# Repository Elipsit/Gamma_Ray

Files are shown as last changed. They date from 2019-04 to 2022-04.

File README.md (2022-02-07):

# Gamma_Ray
## Project Description
This was a personal project to recreate a white paper from Analog Devices on using a PIN photodode as a Gamma Ray detector.

The original insparation was from a Hack-A-Day article [USE A CHEAP PIN DIODE AS A GEIGER COUNTER](https://hackaday.com/blog/?s=cheap+pin+diode)

## Results

The project was successful and when the comparator setpoint was set correctly it will chatter when placed near gamma ray emitting sources or strong background radiation.

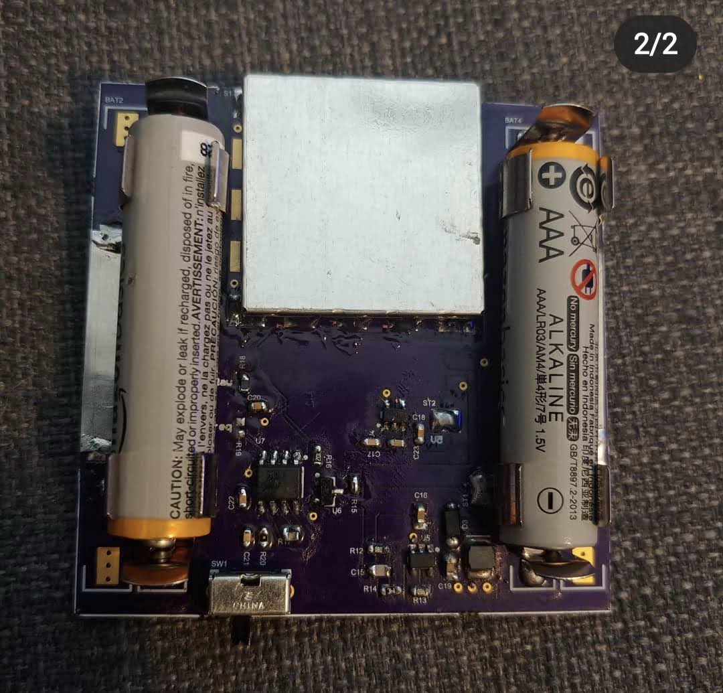
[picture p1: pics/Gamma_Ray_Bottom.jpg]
Bottom Pic


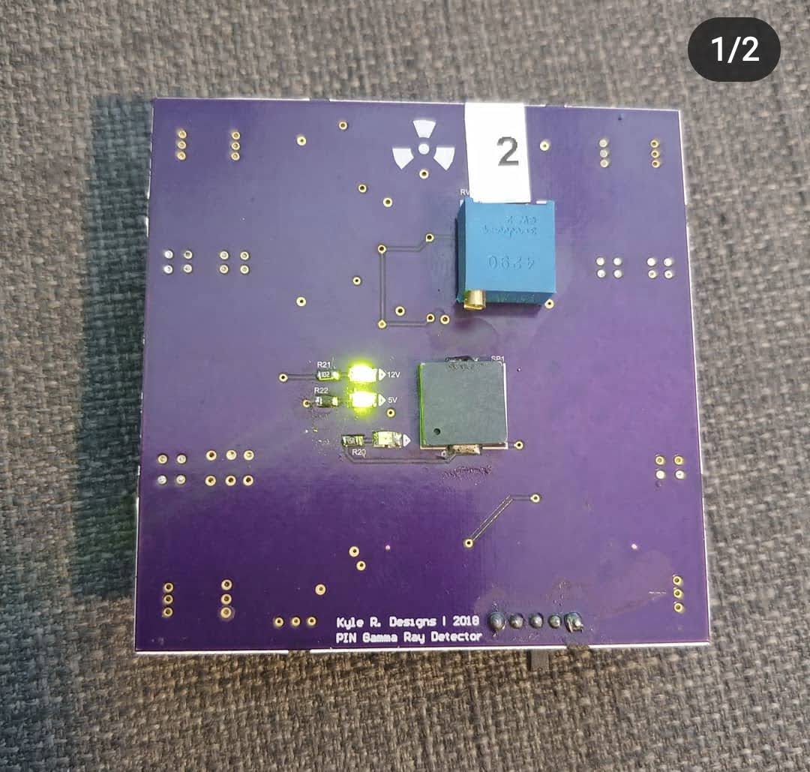
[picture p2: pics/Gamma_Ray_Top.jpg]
Top


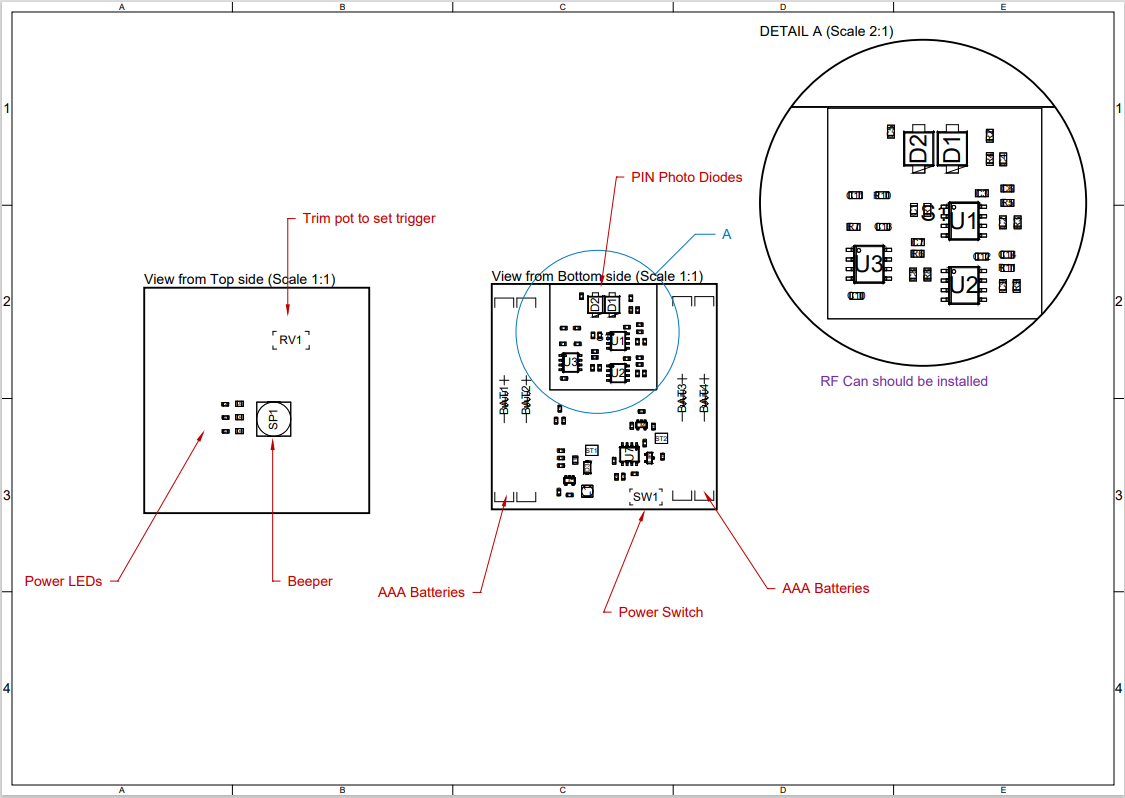
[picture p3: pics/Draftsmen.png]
draftsmen


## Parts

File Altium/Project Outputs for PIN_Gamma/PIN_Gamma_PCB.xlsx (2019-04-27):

Comment | Description | Designator | Digikey | Digikey Part | Digikey PartC | Digikey PartF | Footprint | LibRef | Quantity
U/MAX4477ASA+-ND | Dual Low-Noise, Low-Distortion, Wide-Band, Rail-to-Rail Op Amps | U1, U2 |  |  |  |  | SO8 | U/MAX4477ASA+-ND | 2
U/MAX987ESA+-ND | Comparator General Purpose CMOS, Push-Pull, Rail-to-Rail, TTL 8-SO | U3 |  |  |  |  | SO8 | U/MAX987ESA+-ND | 1
U/LM555CMX | 555 Type, Timer/Oscillator (Single) IC 8-SOIC | U7 |  |  |  |  | SO8 | U/LM555CMX | 1
U/AP1150ADS50 | IC REG LINEAR 5V 200MA SOT23-5 | U4 |  | AP1150ADS50CT-ND |  |  | SOT23-5 | U/AP1150ADS50 | 1
U/2N3904/SOT23 | TRANS NPN 40V 0.2A SOT23 | U6 |  | MMBT3904LT3GOSCT-ND |  |  | SOT23-3 | U/2N3904/SOT23 | 1
SW/SPDT/THT | SWITCH SLIDE SPDT 200MA 30V | SW1 |  | A107673-ND |  |  | SW/SPDT/THT | SW/SPDT/THT | 1
SP/Piezo | AUDIO PIEZO TRANSDUCER Max 12.5V 4KHZ SMD | SP1 |  | 490-9647-1-ND |  |  | AUDIO PIEZO | SP/Piezo | 1
Shark Tooth | Sharks Tooth Small | ST1, ST2 |  |  |  |  | SHARKTOOTH | Shark Tooth | 2
RV/10K/25Turn | TRIMMER 10K OHM 0.5W TH | RV1 |  | A105870-ND |  |  | 10K/25TN | RV/10K/25Turn | 1
RF Shield | SMS-403C & SMS-403F RF Shield Cover 1.058" (26.87mm) X 1.058" (26.87mm) Non-Vented Surface Mount | S1 |  |  | 1798-1210-ND | 1798-1211-1-ND | RF SHIELD | RF Shield | 1
R/976K/0603 | RES SMD 976K OHM 1% 1/10W 0603 | R13 |  | 311-976KHRCT-ND |  |  | R/0603 | R/976K/0603 | 1
R/287r/0603 | RES SMD 287 OHM 1% 1/10W 0603 | R22, R23 |  | 311-287HRCT-ND |  |  | R/0603 | R/287r/0603 | 2
R/150K/0603 | RES SMD 150K OHM 1% 1/10W 0603 | R10 |  | 311-150KGRDKR-ND |  |  | R/0603 | R/150K/0603 | 1
R/118K/0603 | RES SMD 118K OHM 1% 1/10W 0603 | R12 |  | 311-118KHRCT-ND |  |  | R/0603 | R/118K/0603 | 1
R/100K/0603 | RES SMD 100K OHM 1% 1/10W 0603 | R7 |  | 311-100KHRCT-ND |  |  | R/0603 | R/100K/0603 | 1
R/13K7/0603 | RES SMD 13.7K OHM 1% 1/10W 0603 | R14 |  | 311-13.7KHRCT-ND |  |  | R/0603 | R/13K7/0603 | 1
R/10M/0603 | RES SMD 10M OHM 5% 1/10W 0603 | R1, R4 |  | RMCF0603JT10M0CT-ND |  |  | R/0603 | R/10M/0603 | 2
R/10K/0603 | RES SMD 10K OHM 5% 1/10W 0603 | R3, R8, R9, R17, R20 |  | 311-10KGRCT-ND |  |  | R/0603 | R/10K/0603 | 5
R/1M/0603 | RES SMD 1M OHM 0.1% 1/16W 0603 | R2 |  | A119955CT-ND |  |  | R/0603 | R/1M/0603 | 1
R/1K/0603 | RES SMD 1K OHM 5% 1/10W 0603 | R5, R6, R11, R16, R21 |  | 311-1.0KGRCT-ND |  |  | R/0603 | R/1K/0603 | 5
R/0r/0603 | RES SMD 0 OHM JUMPER 1/10W 0603 | R15, R18, R19 |  | 311-0.0GRCT-ND |  |  | R/0603 | R/0r/0603 | 3
LMR62014 | Boost Switching Regulator IC Positive Adjustable 3V 1 Output 1.8A (Switch) SC-74A, SOT-753 | U5 |  |  |  |  | SOT23-5 | U/LMR62014XMF/NOPBCT-ND | 1
L/10uH/SMD | 10µH Semi-Shielded Wirewound Inductor 1A 276 mOhm Max Nonstandard | L1 |  | SRN3015-100MCT-ND |  |  | INDP3030X15N | L/10uH/SMD | 1
D/VBPW34S | PHOTODIODE PIN HI SPEED HI SENS | D1, D2 |  |  |  |  | VBPW34S | D/VBPW34S | 2
D/MBR1020VL | Diode Schottky 20V 1A Surface Mount SOD-123F | D3 |  | MBR1020VLCT-ND |  |  | SOD-123F | D/MBR1020VL | 1
D/LEDR/0805 | LED GREEN CLEAR 2V 0805 SMD | D6 |  | 160-1427-1-ND |  |  | D/0805 | D/LEDR/0805 | 1
D/LEDG/0805 | LED GREEN CLEAR 2.1V 0805 SMD | D4, D5 |  | 160-1423-1-ND |  |  | D/0805 | D/LEDG/0805 | 2
C/1000P/0603 | CAP CER 1000PF 50V C0G/NP0 0603 | C6 | 1276-1091-1-ND |  |  |  | C/0603 | C/1000P/0603 | 1
C/330P/0805 | CAP CER 330PF 50V C0G/NP0 0805 | C15 | 1276-2645-1-ND |  |  |  | C/0603 | C/330P/0805 | 1
C/100P/0603 | CAP CER 100PF 50V C0G/NP0 0603 | C20 | 399-1061-1-ND |  |  |  | C/0603 | C/100P/0603 | 1
C/4U7/0805 | CAP CER 4.7UF 50V X5R 0805 | C16 | 1276-1860-1-ND |  |  |  | R/0805 | C/4U7/0805 | 1
C/4P7/0603 | CAP CER 4.7PF 50V C0G/NPO 0603 | C1, C2, C8, C9 | 311-1740-1-ND |  |  |  | C/0603 | C/4P7/0603 | 4
C/2U2/0603 | 2.2µF ±10% 10V Ceramic Capacitor X5R 0603 (1608 Metric) | C19 | 490-1545-1-ND |  |  |  | C/0603 | C/2U2/0603 | 1
C/1U/0603 | CAP CER 1UF 50V X5R 0603 | C17, C18 | 1276-1860-1-ND |  |  |  | C/0603 | C/1U/0603 | 2
C/0.1U/0603 | CAP CER 0.1UF 50V X7R 0603 | C3, C4, C10, C11, C12, C13, C22, C23 |  | 399-7845-1-ND |  |  | C/0603 | C/0.1U/0603 | 8
C/0.012U/0603 | CAP CER 0.012UF 50V X7R 0603 | C21 |  | 1276-1785-1-ND |  |  | C/0603 | C/0.012U/0603 | 1
C/0.01U/0603 | CAP CER 0.01UF 50V X7R 0603 | C5, C7, C14 |  | 399-1091-1-ND |  |  | C/0603 | C/0.01U/0603 | 3
BAT/AAA_Clips/SMT | AAA 1.5V SMT Clips | BAT1, BAT2, BAT3, BAT4 |  | 36-55-ND |  |  | AAA_BATTERY_SMT | BAT/AAA_Clips/SMT | 4

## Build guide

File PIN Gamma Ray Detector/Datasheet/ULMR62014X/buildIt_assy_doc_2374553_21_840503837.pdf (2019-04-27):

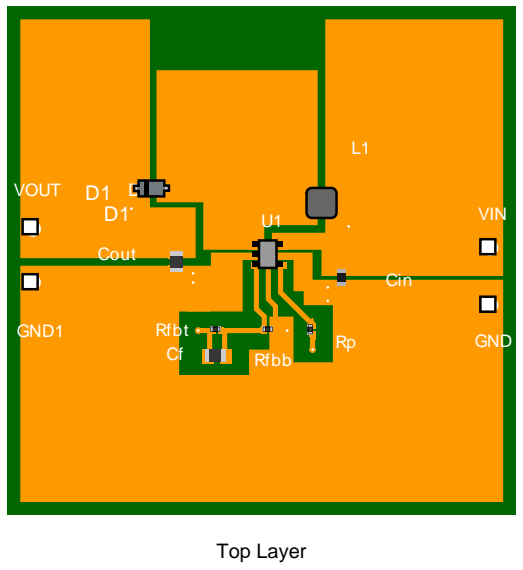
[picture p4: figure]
Cout; Rfbb; Rfbt; Cin; VOUT; GND1; GND; VIN; Top Layer
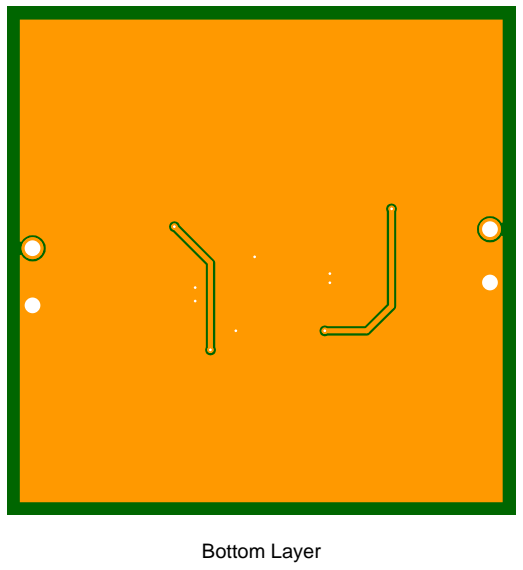
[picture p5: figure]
Bottom Layer

Copyright © 2017, Texas Instruments Incorporated | 1 | ti.com/webench

WEBENCH®
Assembly Document LMR62014XMF/NOPB December 27, 2017 11:22:02 GMT-08:00

## WEBENCH ® Assembly Document

Design : 2374553/21 LMR62014XMF/NOPB
LMR62014XMF/NOPB 5.0V-5.0V to 12.00V @ 0.2A

VinMin = 5.0V
VinMax = 5.0V
Vout = 12.0V
Iout = 0.2A

Device = LMR62014XMF/NOPB
Topology = Boost
Created = 2017-12-27 07:08:34.710 BOM Cost = $0.85
Total Pd = 0.34W
Footprint = 70.0 mm²
BOM Count = 9

## General Description

This is a WEBENCH assembly document for LMR62014XMF/NOPB to support the Build-It Lite feature offered by WEBENCH Power Designer Tool or the full Build-It feature that includes an orderable blank board from our distribution partners. This document serves as a basic guidance on mounting the Build-It kit components onto a blank board and provides the basic setups for testing the fully assembled evaluation module. For more information on the IC performance and other resource, please refer Design Assistance section below.

### My Comments

No comments

Design

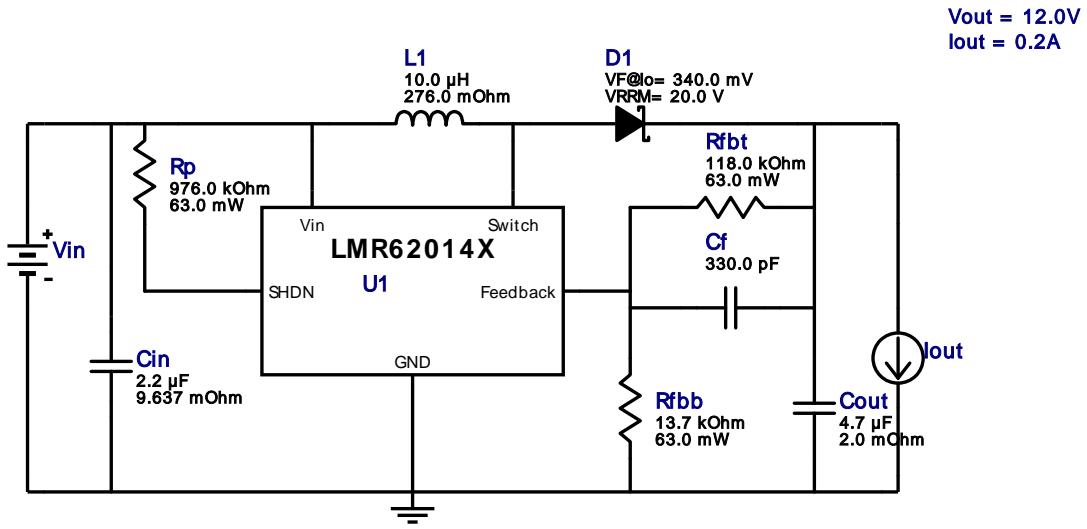
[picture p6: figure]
Cin 2.2 µF; 9.637 mOhm; Cout; 4.7 µF 2.0 mOhm; D1 VF@Io= 340.0 mV VRRM= 20.0 V; L1 10.0 µH 276.0 mOhm; Rfbb 13.7 kOhm 63.0 mW; Rfbt 118.0 kOhm 63.0 mW Rp 976.0 kOhm 63.0 mW; LMR62014X; Vin; Switch; SHDN; Feedback; GND; Vout = 12.0V Iout = 0.2A; Iout

Copyright © 2017, Texas Instruments Incorporated | 2 | ti.com/webench

## Mechanical BOM

# | WEBENCH Name | Altrium Comp Type | Part Name | FootPrint

No Mechanical BOM Data

## Electrical BOM

# | Component Name(s) | Part Number | Manufacture | Qty Unit Price | Top View

1. | L1 | SRN3015-100M | Bourns | 1 | $0.39

SRN3015 0.0
2. | Cout | GRM21BR61E475MA12L | MuRata | 1 | $0.16
0805 0.0
3. | Cf | CL21C331JBANFNC | Samsung
Electro-Mechanics
1 | $0.1
0805 0.0
4. | Rfbt | CRCW0402118KFKED | Vishay-Dale | 1 | $0.1
0402 0.0
5. | Rp | CRCW0402976KFKED | Vishay-Dale | 1 | $0.1
0402 0.0
6. | Cin | GRM188R61A225KE34D | MuRata | 1 | $0.15
0603 0.0
7. | U1 | LMR62014XMF/NOPB | Texas
Instruments
1 | $1.5
DBV0005A 0.0
8. | D1 | MBR1020VL | Fairchild
Semiconductor

1 $0.39
SOD-123F 0.0
9. | Rfbb | CRCW040213K7FKED | Vishay-Dale | 1 | $0.1
0402 0.0


Copyright © 2017, Texas Instruments Incorporated | 3 | ti.com/webench

## Component Testing

Some published data on components in datasheets such as Capacitor ESR and Inductor DC resistance is based on conservative values that will guarantee that the components always exceed the specification. For design purposes it is usually better to work with typical values. Since this data is not always available it is a good practice to measure the Capacitance and ESR values of Cin and Cout, and the inductance and DC resistance of L1 before assembly of the board. Any large discrepancies in values should be electrically simulated in WEBENCH to check for instabilities and thermally simulated in WebTHERM to make sure critical temperatures are not exceeded.

## Soldering Component to Board

If board assembly is done in house it is best to tack down one terminal of a component on the board then solder the other terminal. For surface mount parts with large tabs, such as the DPAK, the tab on the back of the package should be pre-tinned with solder, then tacked into place by one of the pins. To solder the tab town to the board place the iron down on the board while resting against the tab, heating both surfaces simultaneously. Apply light pressure to the top of the plastic case until the solder flows around the part and the part is flush with the PCB. If the solder is not flowing around the board you may need a higher wattage iron (generally 25W to 30W is enough).

## Initial Startup of Circuit

It is best to initially power up the board by setting the input supply voltage to the lowest operating input voltage 5.0V and set the input supply's current limit to zero. With the input supply off connect up the input supply to Vin and GND. Connect a digital volt meter and a load if needed to set the minimum Iout of the design from Vout and GND. Turn on the input supply and slowly turn up the current limit on the input supply. If the voltage starts to rise on the input supply continue increasing the input supply current limit while watching the output voltage. If the current increases on the input supply, but the voltage remains near zero, then there may be a short or a component misplaced on the board. Power down the board and visually inspect for solder bridges and recheck the diode and capacitor polarities. Once the power supply circuit is operational then more extensive testing may include full load testing, transient load and line tests to compare with simulation results.

## Load Testing

The setup is the same as the initial startup, except that an additional digital voltmeter is connected between Vin and GND, a load is connected between Vout and GND and a current meter is connected in series between Vout and the load. The load must be able to handle at least rated output power + 50% ( 7.5 watts for this design). Ideally the load is supplied in the form of a variable load test unit. It can also be done in the form of suitably large power resistors. When using an oscilloscope to measure waveforms on the prototype board, the ground leads of the oscilloscope probes should be as short as possible and the area of the loop formed by the ground lead should be kept to a minimum. This will help reduce ground lead inductance and eliminate EMI noise that is not actually present in the circuit.

## Design Inputs

# | Name | Value | Description

1. Iout | 200.0 mA | Maximum Output Current
2. VinMax | 5.0 V | Maximum input voltage
3. VinMin | 5.0 V | Minimum input voltage
4. Vout | 12.0 V | Output Voltage
5. base_pn | LMR62014X | Base Product Number
6. source | DC | Input Source Type
7. Ta | 30.0 degC | Ambient temperature

## Design Assistance

1. LMR62014X Product Folder : http://www.ti.com/product/LMR62014 : contains the data sheet and other resources.

Copyright © 2017, Texas Instruments Incorporated | 4 | ti.com/webench

Texas Instruments' WEBENCH simulation tools attempt to recreate the performance of a substantially equivalent physical implementation
of the design. Simulations are created using Texas Instruments' published specifications as well as the published specifications of other device manufacturers. While Texas Instruments does update this information periodically, this information may not be current at the time the simulation is built. Texas Instruments does not warrant the accuracy or completeness of the specifications or any information contained therein. Texas Instruments does not warrant that any designs or recommended parts will meet the specifications you entered, will be suitable for your application or fit for any particular purpose, or will operate as shown in the simulation in a physical implementation. Texas Instruments does not warrant that the designs are production worthy.
You should completely validate and test your design implementation to confirm the system functionality for your application prior to production.
Use of Texas Instruments' WEBENCH simulation tools is subject to Texas Instruments' Site Terms and Conditions of Use. (http://www.ti.com/corp/docs/legal/termsofuse.shtml) Prototype boards based on WEBENCH created designs are provided AS IS without warranty of any kind for evaluation and testing purposes and are subject to the terms of the Evaluation License Agreement. (http://www.ti.com/corp/docs/legal/termsofuse_estore.shtml)

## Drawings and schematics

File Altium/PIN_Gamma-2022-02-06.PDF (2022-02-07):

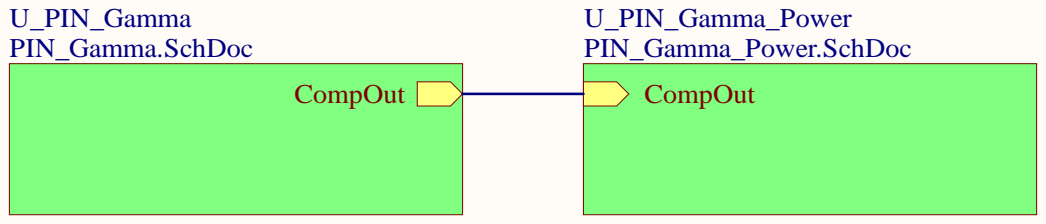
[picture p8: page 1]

Title
PIN Gamma Top Sheet

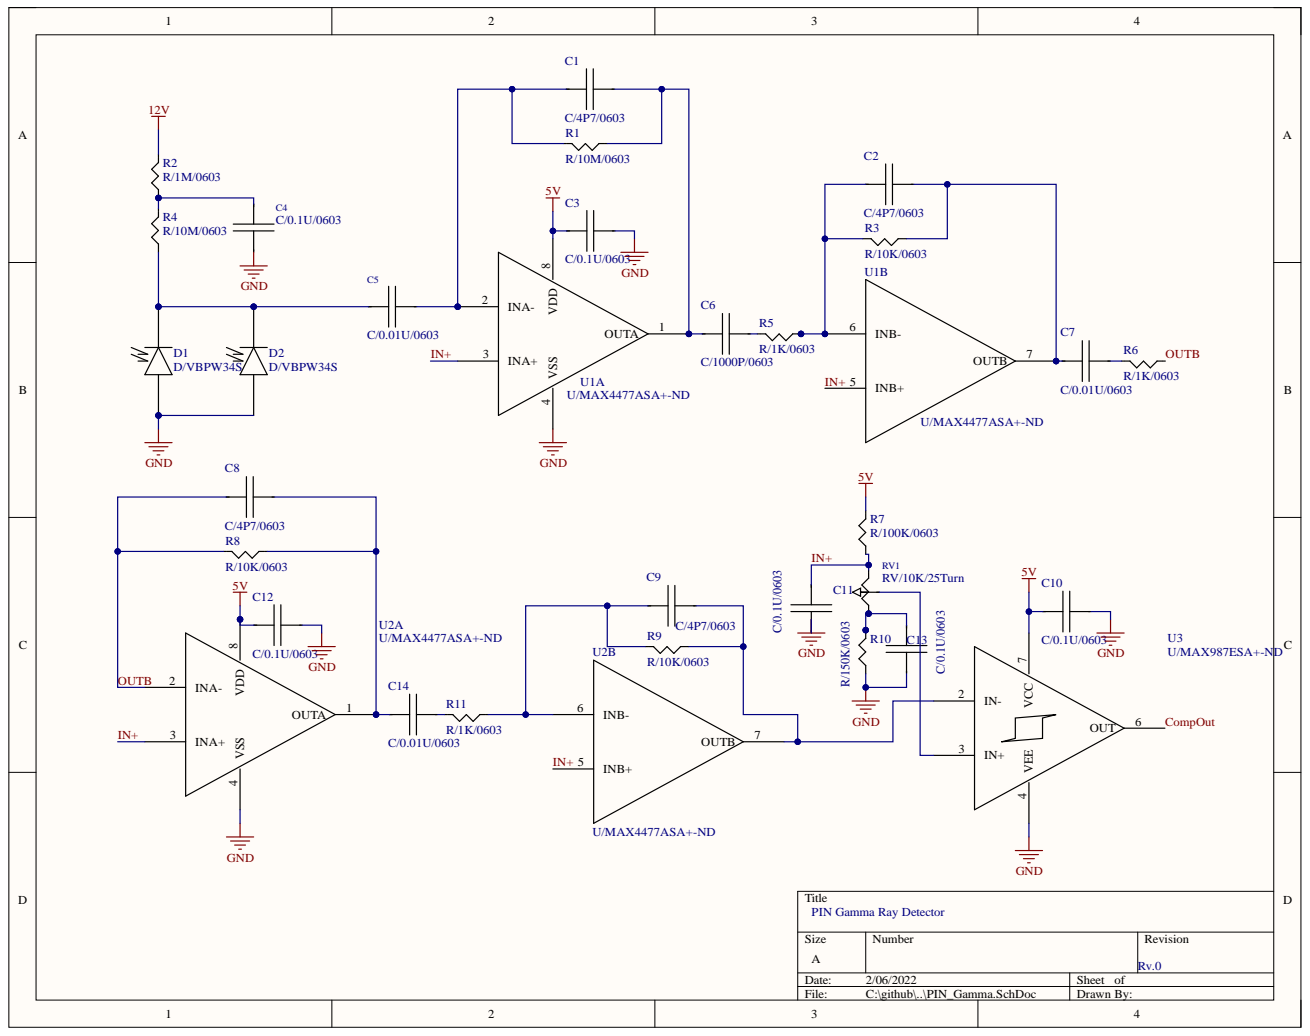
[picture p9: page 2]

Title
PIN Gamma Ray Detector

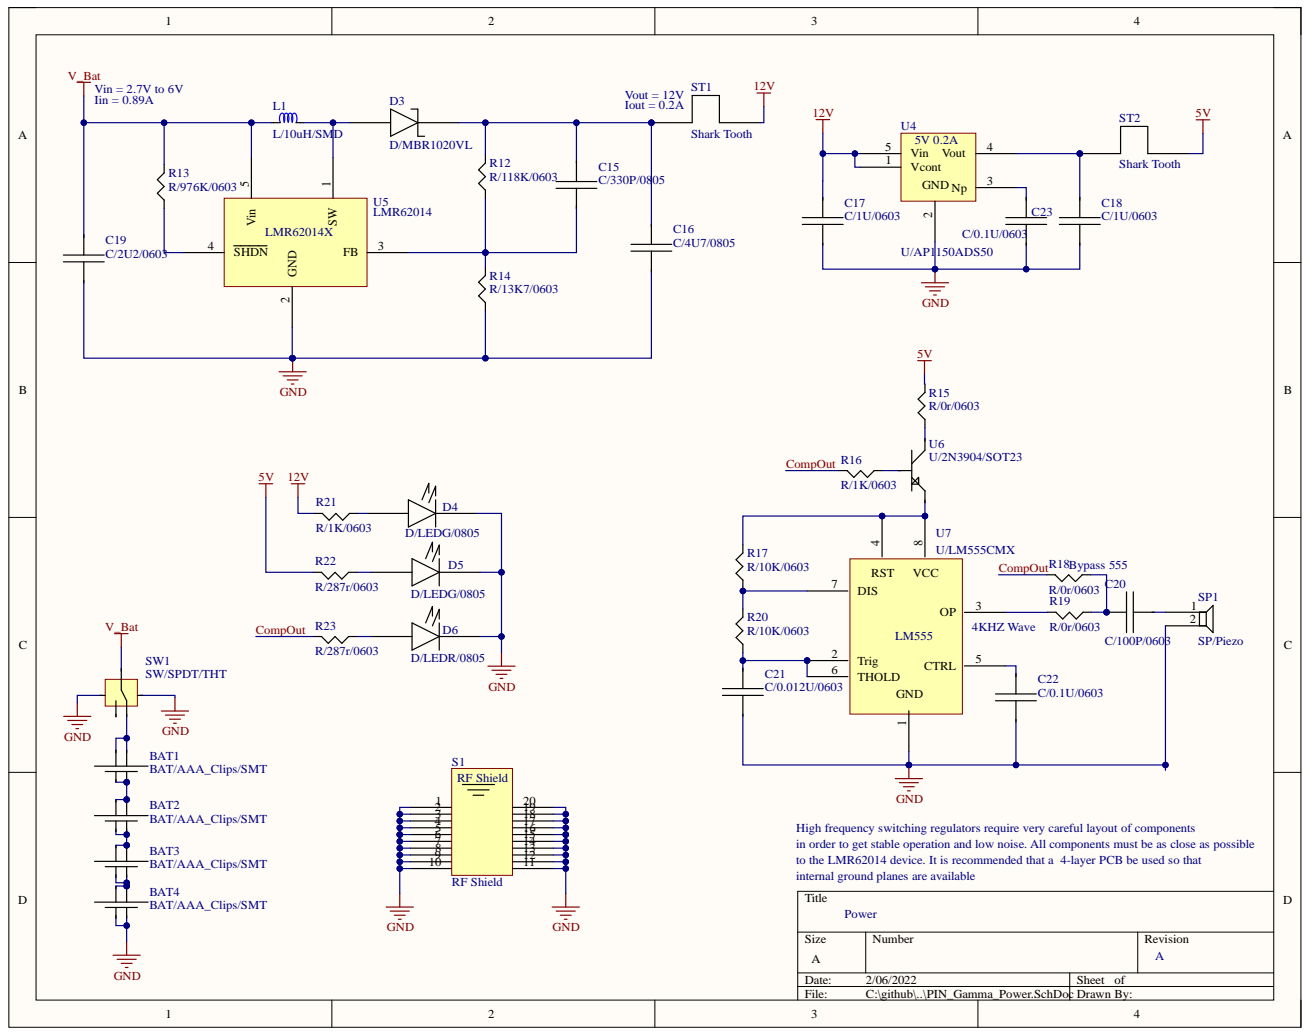
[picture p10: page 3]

High frequency switching regulators require very careful layout of components
in order to get stable operation and low noise. All components must be as close as possible
to the LMR62014 device. It is recommended that a 4-layer PCB be used so that
internal ground planes are available

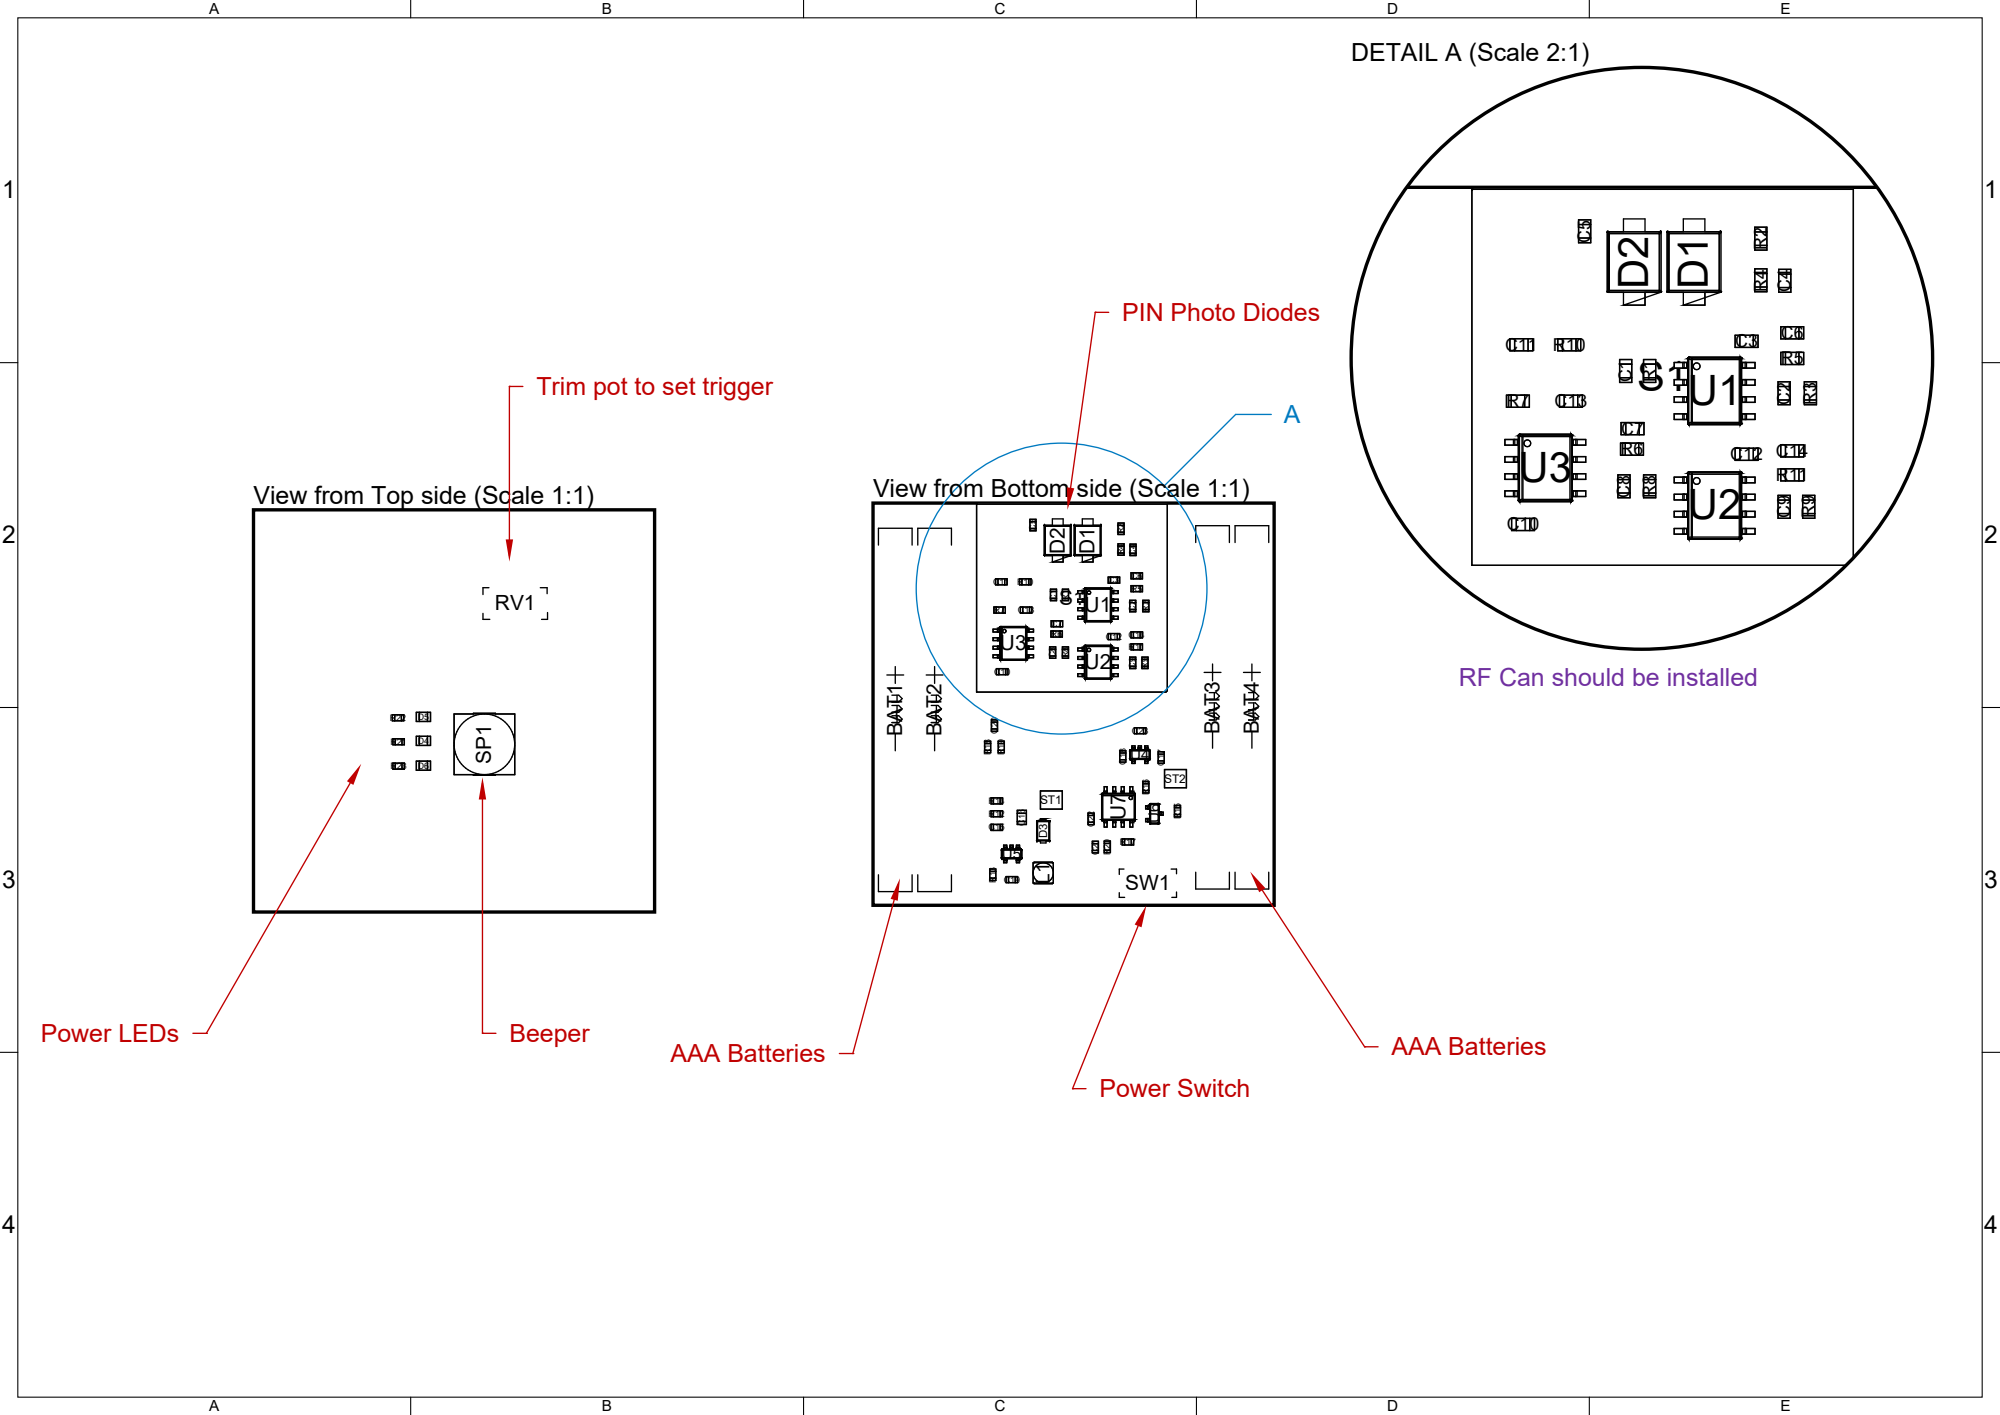
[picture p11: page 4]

Trim pot to set trigger

View from Top side (Scale 1:1)

View from Bottom side (Scale 1:1)

RF Can should be installed

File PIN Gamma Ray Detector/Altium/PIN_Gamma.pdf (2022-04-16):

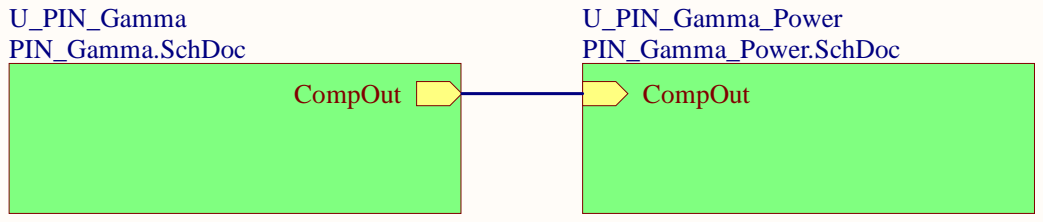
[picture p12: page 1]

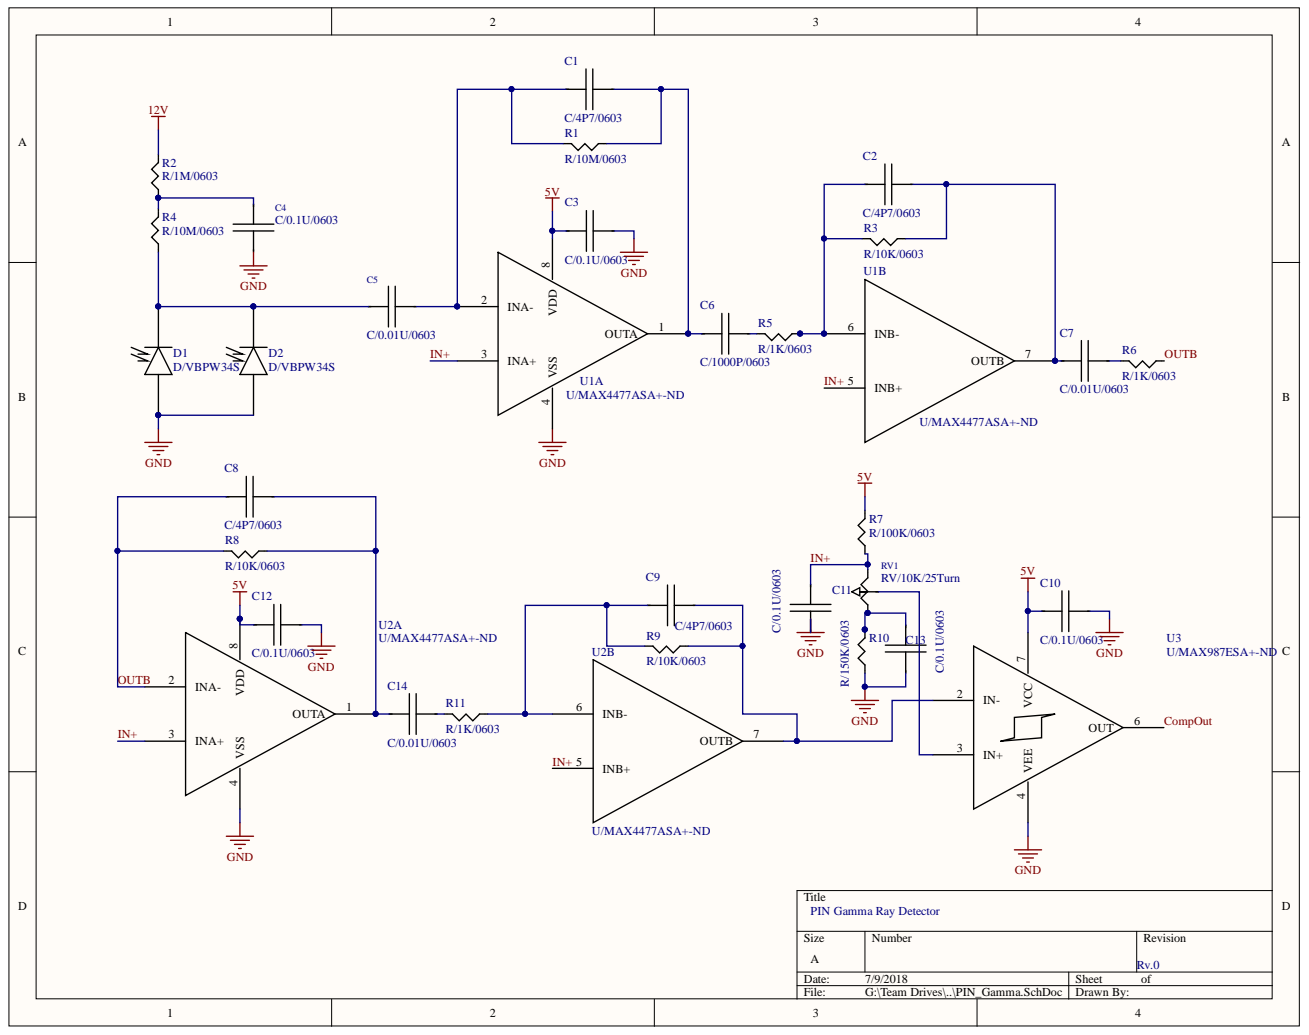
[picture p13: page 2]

Title
PIN Gamma Ray Detector

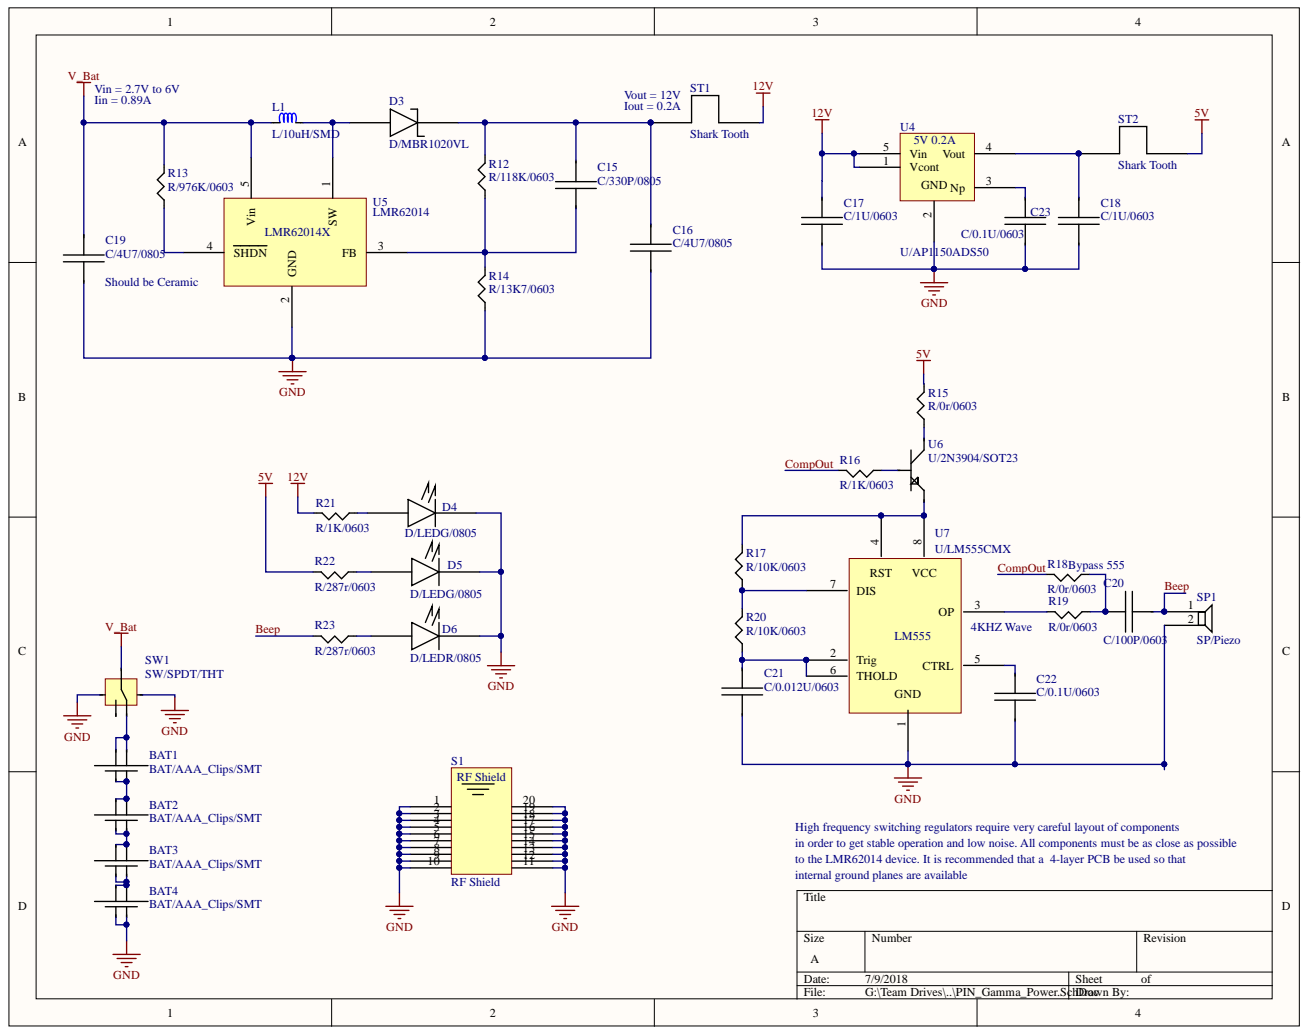
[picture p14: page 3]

High frequency switching regulators require very careful layout of components
in order to get stable operation and low noise. All components must be as close as possible
to the LMR62014 device. It is recommended that a 4-layer PCB be used so that
internal ground planes are available

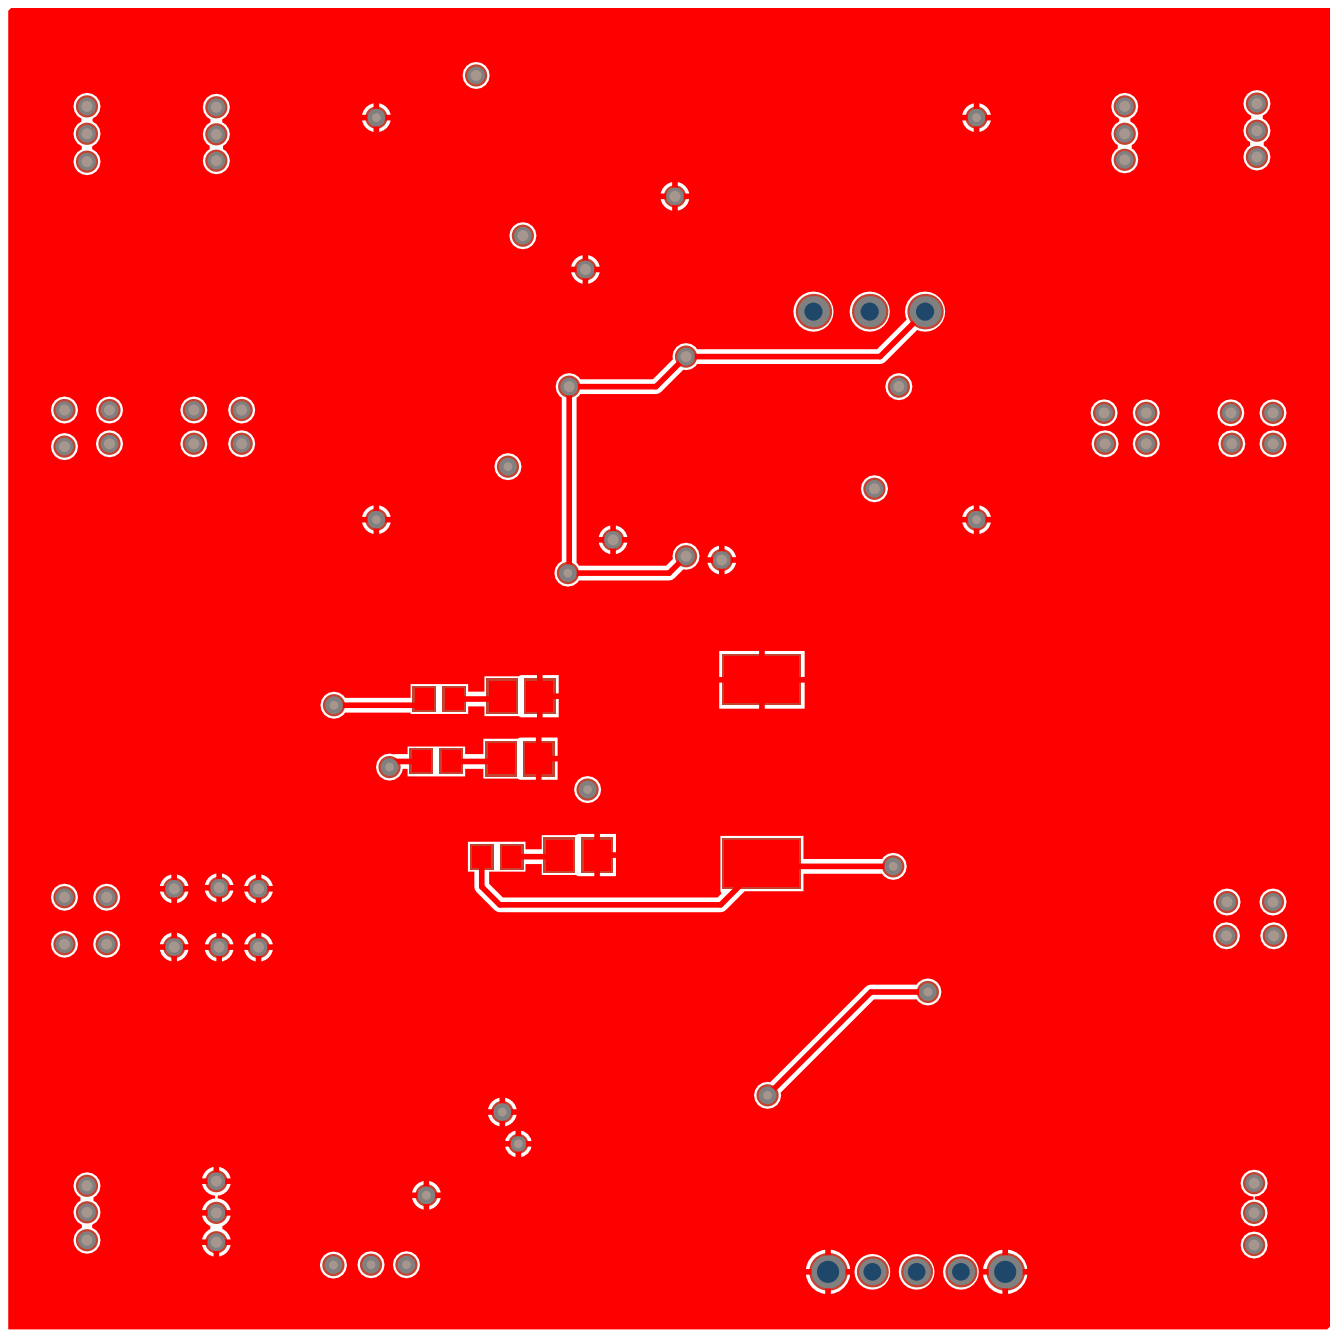
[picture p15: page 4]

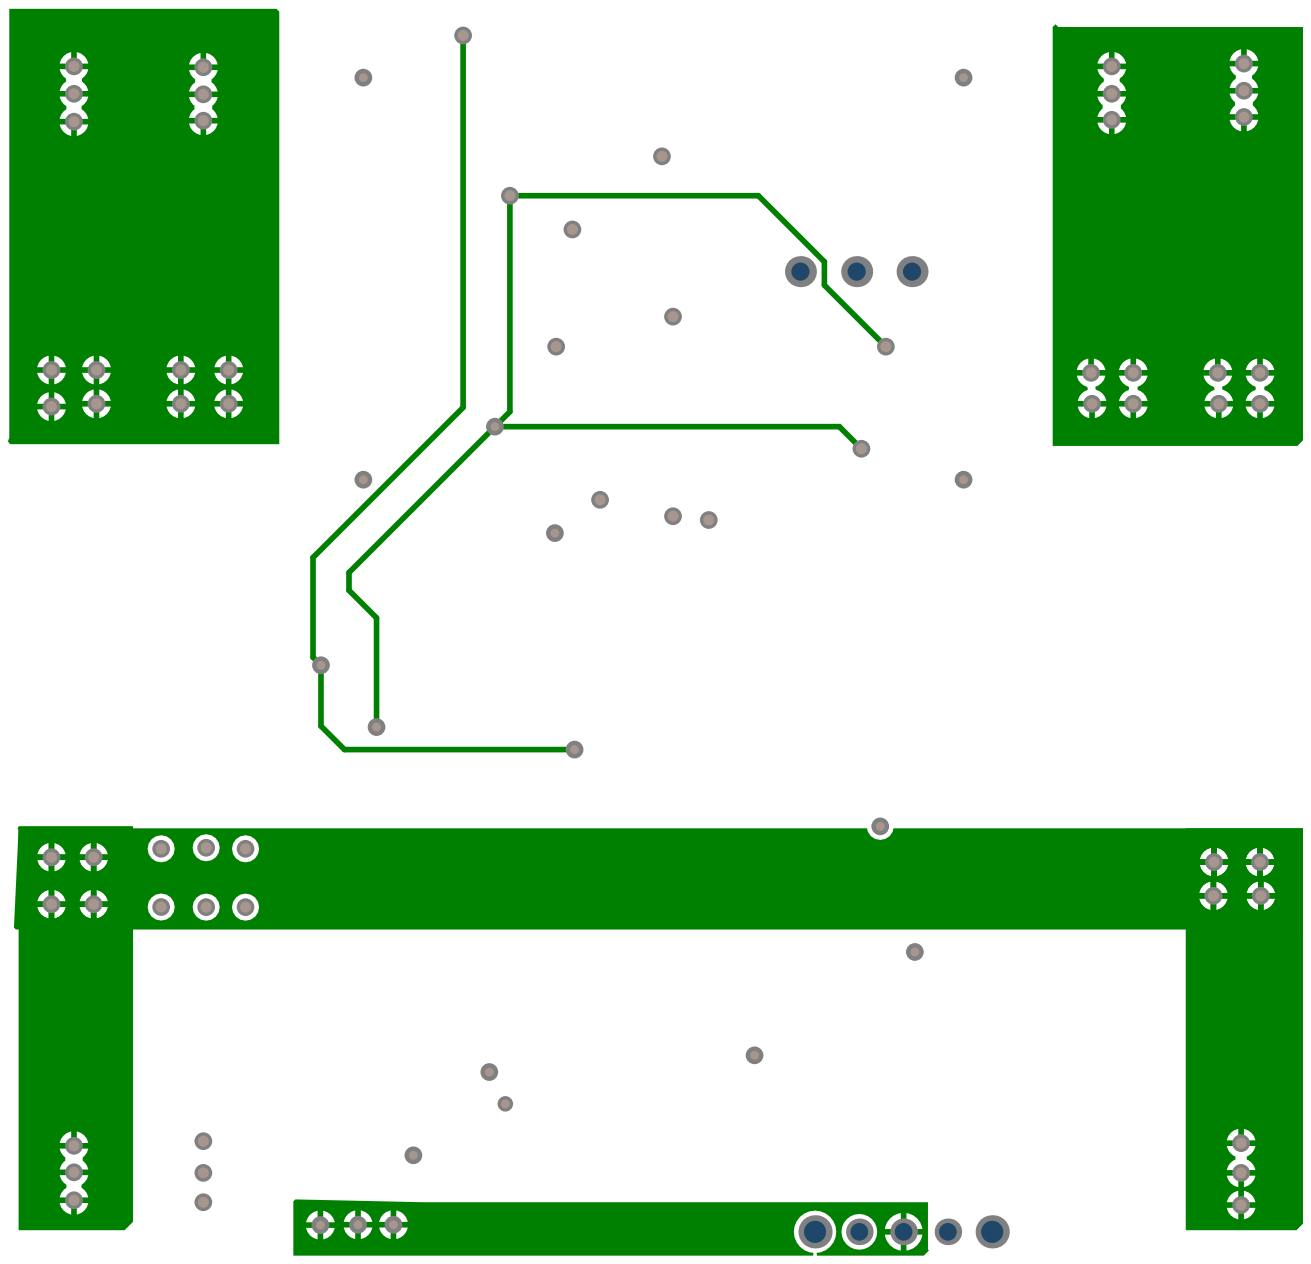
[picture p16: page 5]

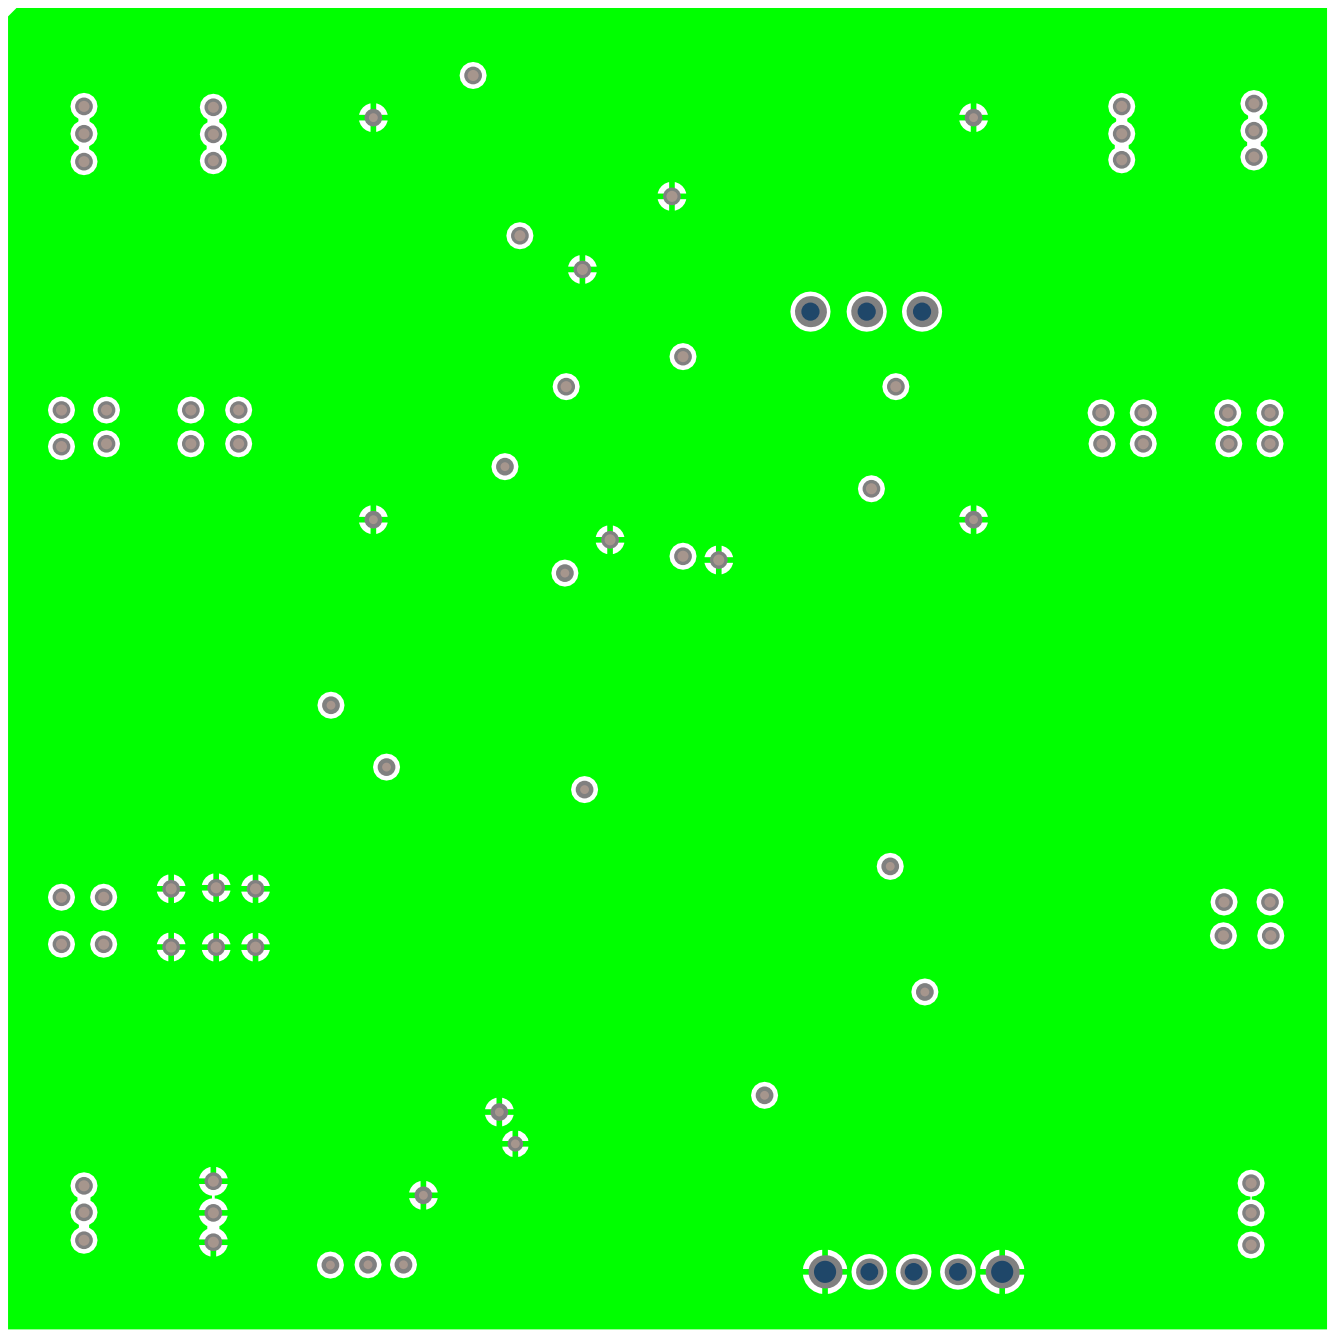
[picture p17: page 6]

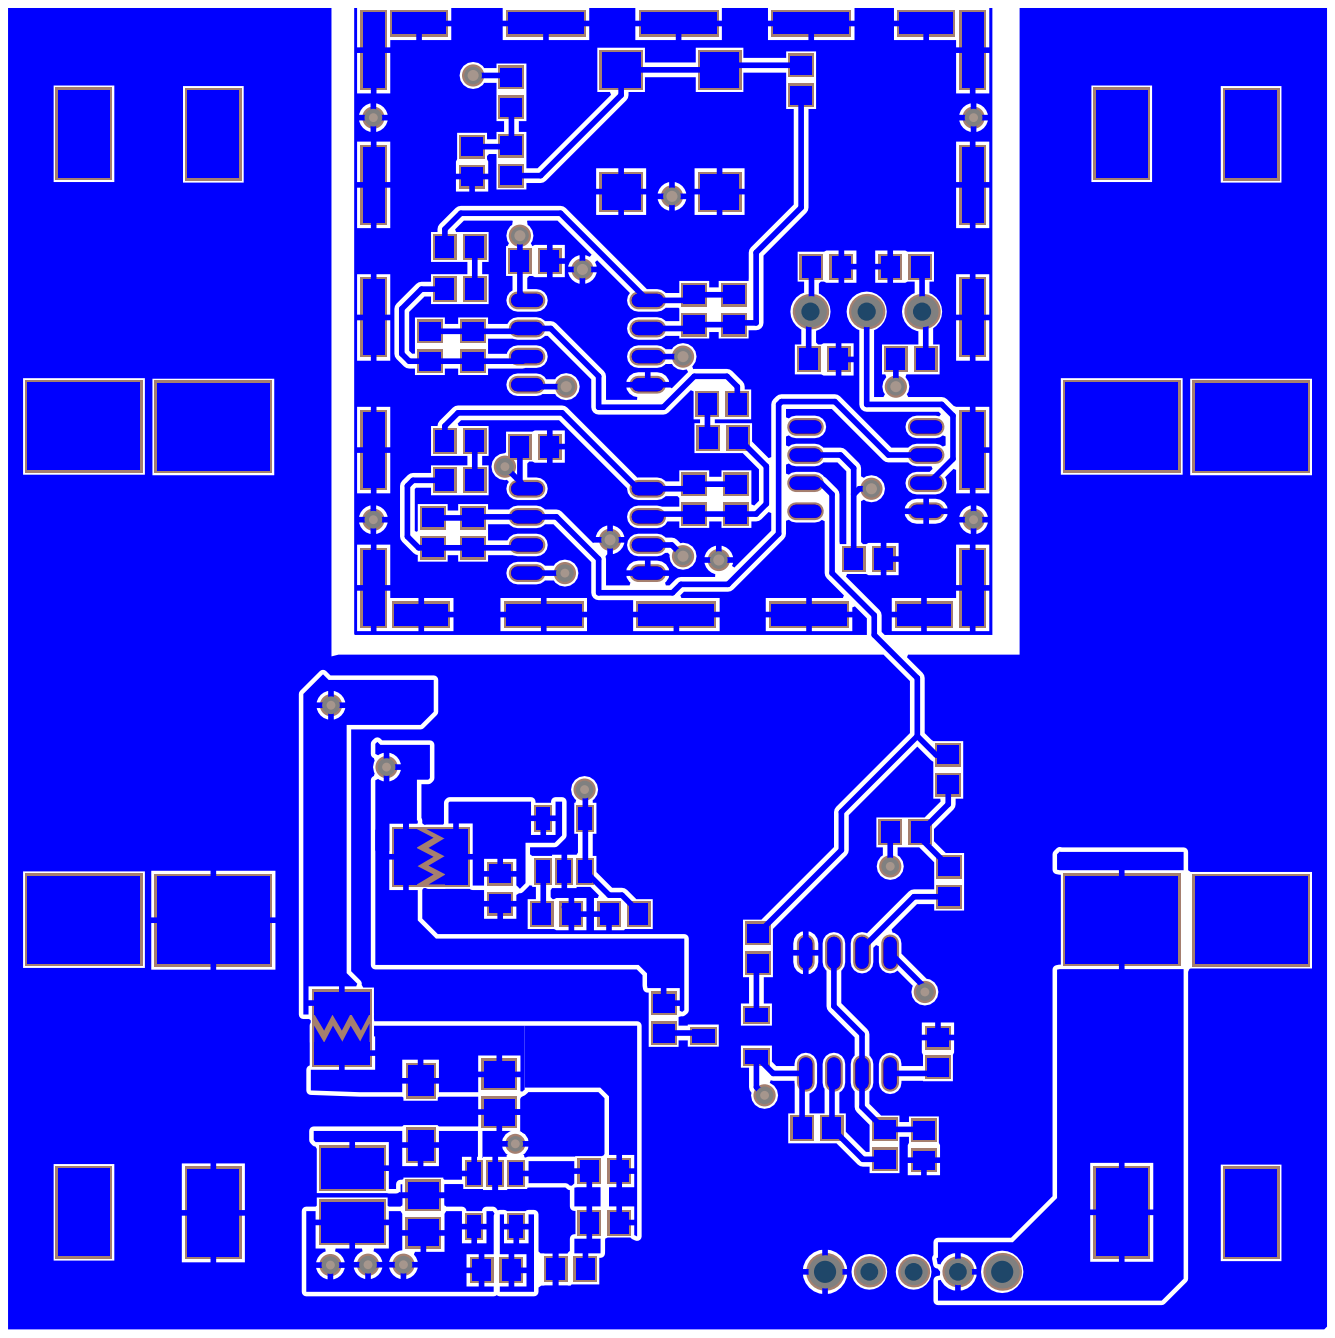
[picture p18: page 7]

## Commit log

2019-04-27 Project added to git
    [PIN_Gamma.PrjPcb, PIN_Gamma.SchDoc, PIN_Gamma_PCB.PcbDoc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]
2022-02-07 updating pics
    [PIN_Gamma.PrjPcb, PIN_Gamma.SchDoc, PIN_Gamma_PCB_MAR20.PcbDoc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]
2022-04-16 adding old files
    [PIN_Gamma.PrjPcb, PIN_Gamma.SchDoc, PIN_Gamma_PCB_July5.PcbDoc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]
